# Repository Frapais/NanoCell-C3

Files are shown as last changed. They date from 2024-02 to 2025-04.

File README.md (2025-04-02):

# NanoCell-C3

This is the repository of my **NanoCell-C3** project, which includes an ESP32 development board I made to simplify the creation of small battery-powered devices for use with Home Assistant and ESPHome.
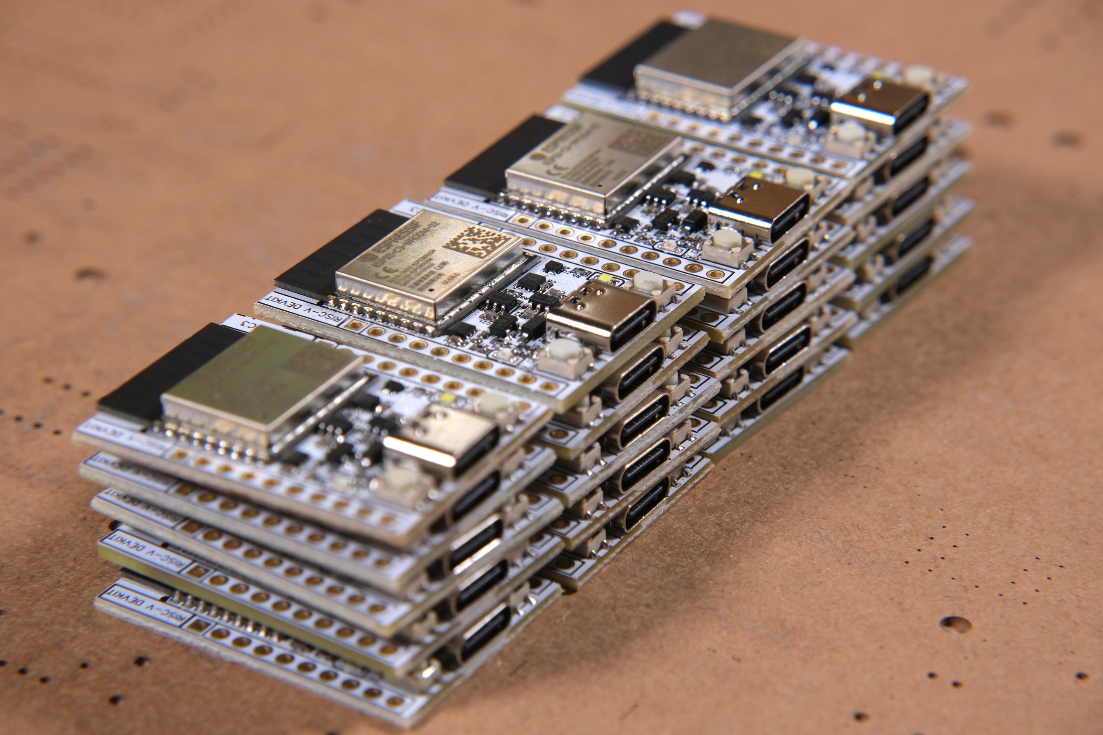
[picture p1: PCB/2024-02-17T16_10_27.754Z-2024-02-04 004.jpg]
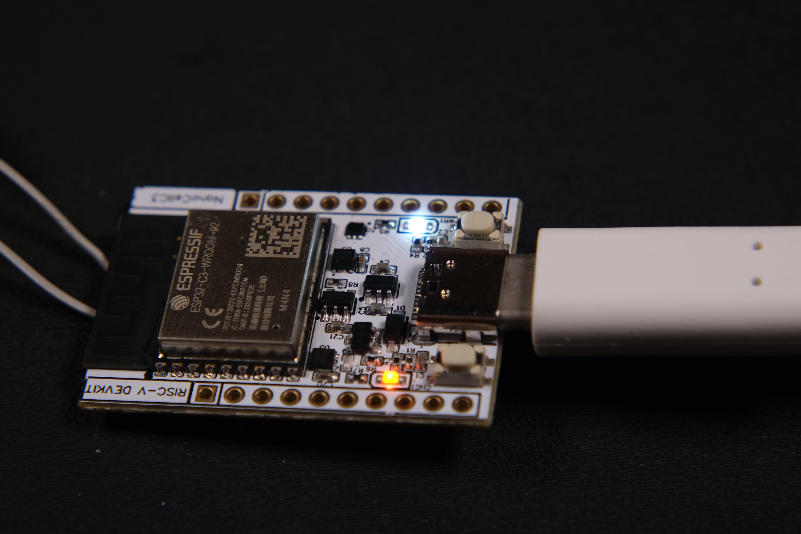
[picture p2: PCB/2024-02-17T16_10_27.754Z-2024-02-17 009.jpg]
|  |  |
|---|---|
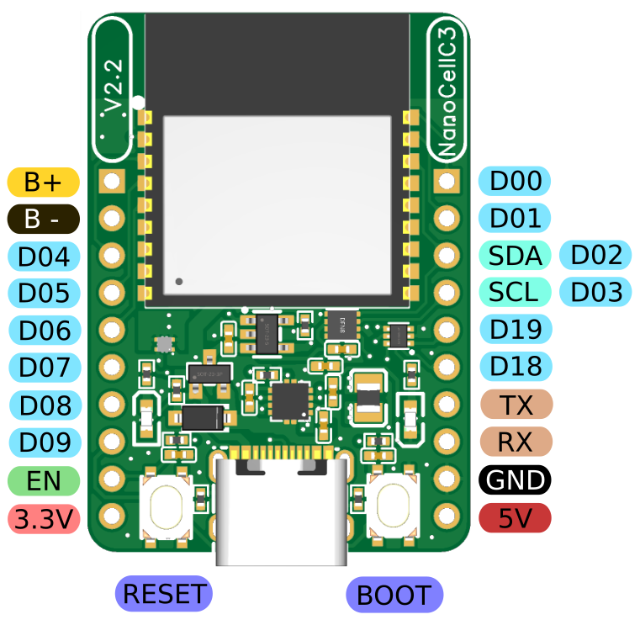
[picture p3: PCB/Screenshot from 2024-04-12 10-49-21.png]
Pinout
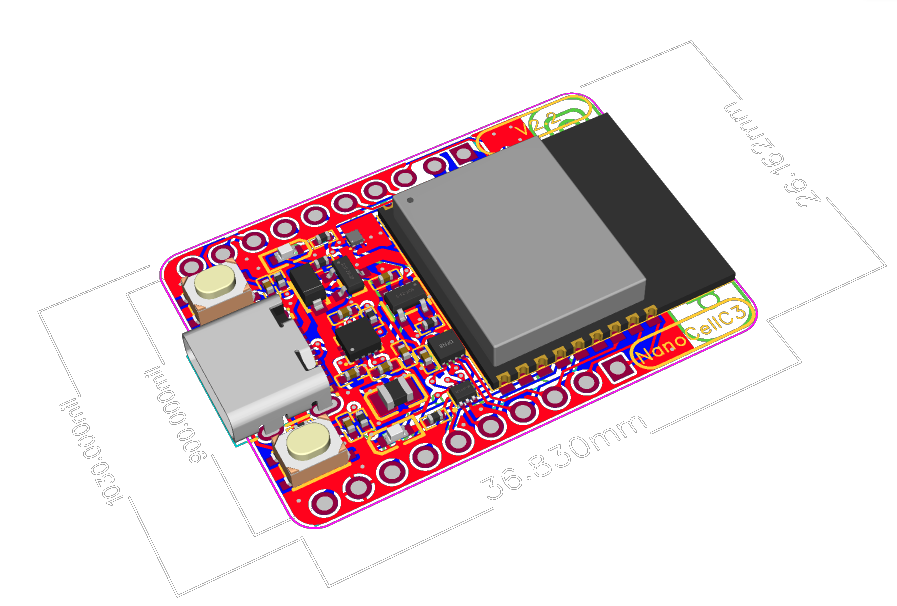
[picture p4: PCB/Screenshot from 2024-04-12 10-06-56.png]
Dimensions
|  |  |

## Description
### Hardware
#### Main Features
* Li-ion/Li-po battery charging & protection ICs
* Accurate battery capacity measurement IC, accessible via I2C on pins 2 and 3.
* USB Type-C port for charging and uploading firmware
* RESET and BOOT pushbuttons
* Charging and USB-power LED indicators
* Breadboard-compatible pin headers breaking out all the pins of ESP32-C3, as well as the USB, battery, and Vcc voltage.

### Tests
| Idle Power Consumption: 66.1μA | Max Charging Current: 464mA | VCC Output @ 4.2V input: 3.356V | VCC Output @ 3V input: 3.359V |
|---|---|---|---|
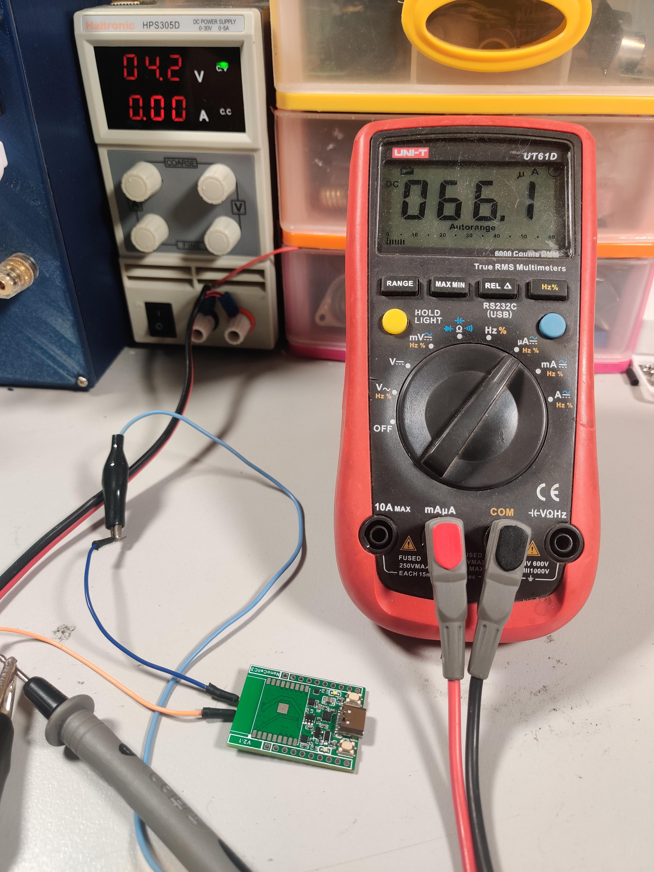
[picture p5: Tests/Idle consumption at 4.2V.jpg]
Idle Power Consumption
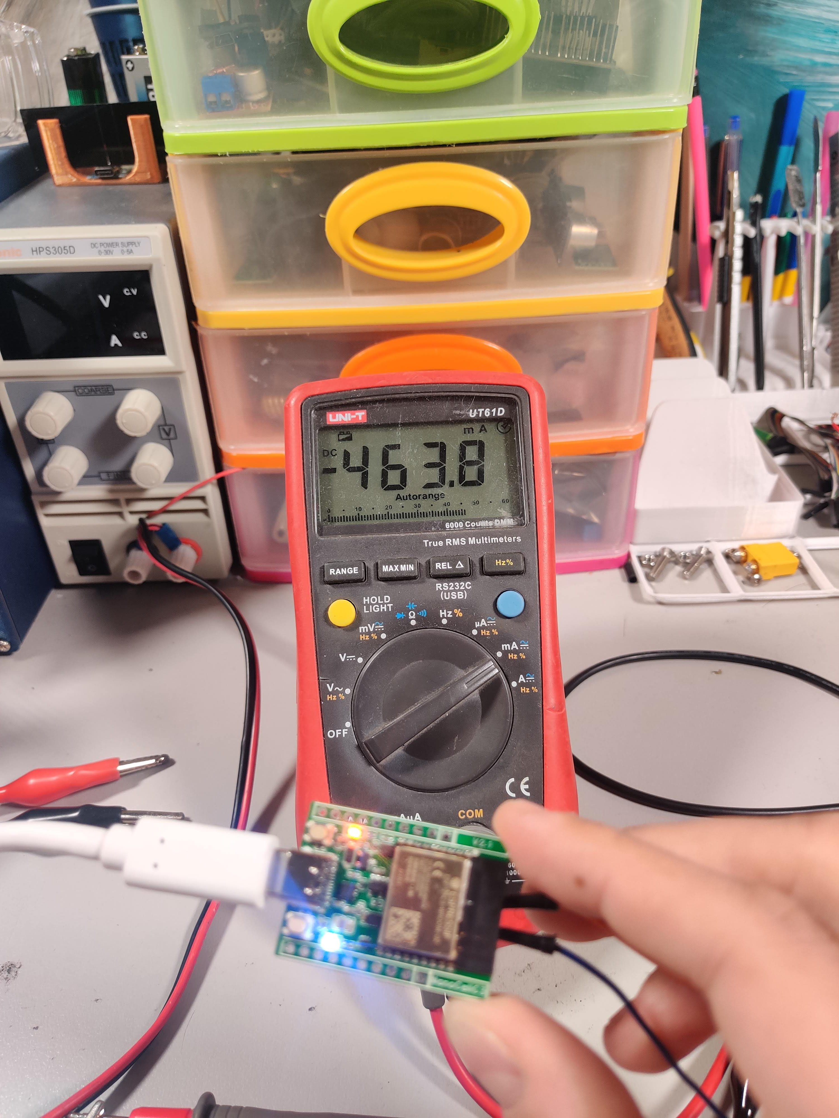
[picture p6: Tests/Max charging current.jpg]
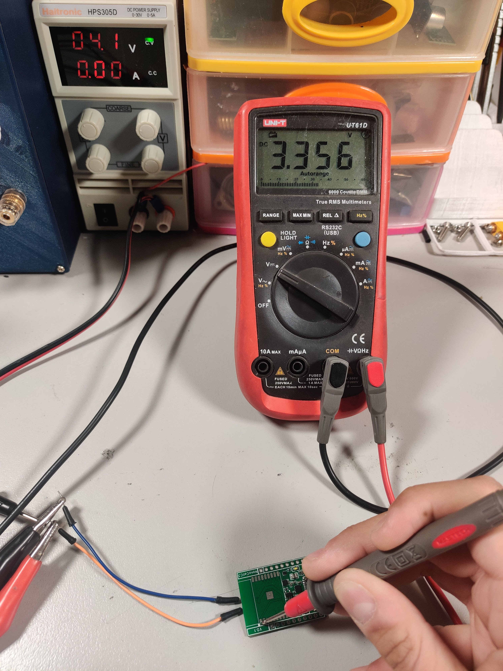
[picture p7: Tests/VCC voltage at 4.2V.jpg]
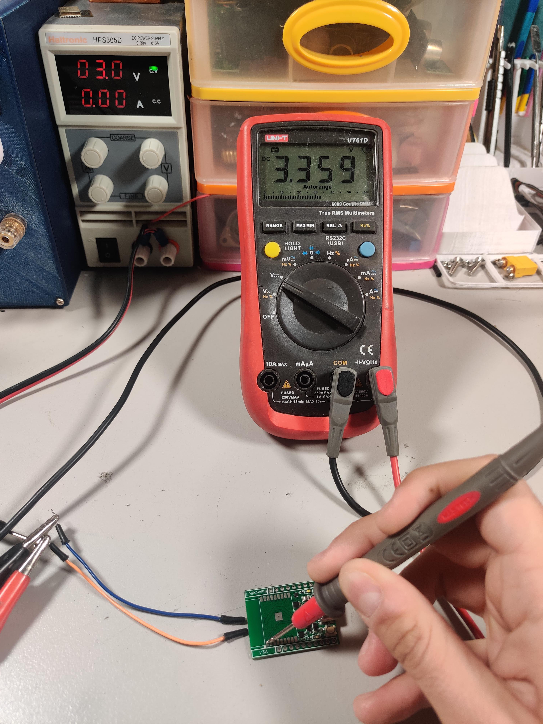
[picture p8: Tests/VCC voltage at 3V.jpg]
|  |  |  |  |

The Idle Power Consumption image shows the consumption of all the components of the board except the ESP32 module, as its consumption fluctuates depending on the tasks it's running. Therefore, if you want to calculate the battery life of your project, you should expect at least 66μA of current, in addition to the current consumption of the ESP32 module.

### Initial Home Assistant setup
#### Requirements:
* Access to Home Assistant Dashboard
* Installed ESPHome plugin

#### Setup process:
1. Connect the NanoCell-C3 board on the computer running Home Assistant, while pressing the BOOT button
2. Open ESPHome, and add a new device as shown [here](https://esphome.io/guides/getting_started_hassio#dashboard-interface)
3. Select "Connect" to upload the initialization firmware on the board, and select the correct port from the popup window. (It usually shows up as a "USB JTAG" device).
4. Wait for the upload to finish, and restart the NanoCell-C3. Now, every time you power on the device, it should connect to your WiFi automatically.
5. Last step, is to go to your Home Assistant settings, and Configure your newly discovered device (assuming it is powered on and visible on the network).

#### Video Tutorial:
https://youtu.be/UaIIV4CaRA4

### Battery Capacity Measurement
The NanoCell-C3 board features the MAX17048 battery capacity measurement IC connected to the respective I2C pins. As there is not complete support for this IC in the [ESPHome](https://esphome.io/index.html), you need to add it as a custom [ESPHome Component](https://esphome.io/components/sensor/custom)

#### I2C Pins of the NanoCell-C3 board
| Function | Pin No |
|---|---|
| SDA | 2 |
| SCL | 3 |

#### Setup process
Inside the [Home Assistant Setup](https://github.com/Frapais/NanoCell-C3/tree/main/Home%20Assistant%20Setup) folder, you will find a YAML file and a HEADER file.
* First, you must copy the header file to your Home Assistant under "/config/esphome/custom_components/MAX17048_component.h".
* Next, you have to create a new ESP32-C3 device from the ESPHome plugin, as described above. (If you haven't already).
* Inside the corresponding YAML file, you must paste the contents of this repo's [YAML]() file, replacing the "***" with your corresponding values.
  
Your YAML file needs to import the "MAX17048_component.h" file in the "includes" section, as well as the "Wire" library in the "libraries section.
Next, you can add an i2c sensor using the "custom" platform and include the corresponding "lambda" section to get the values from the MAX17048 Battery Measurement IC.

**Voila!** You can now monitor your battery status from Home Assistant with accuracy! I used Graphana to plot the Li-Ion battery's capacity over time in the following image:
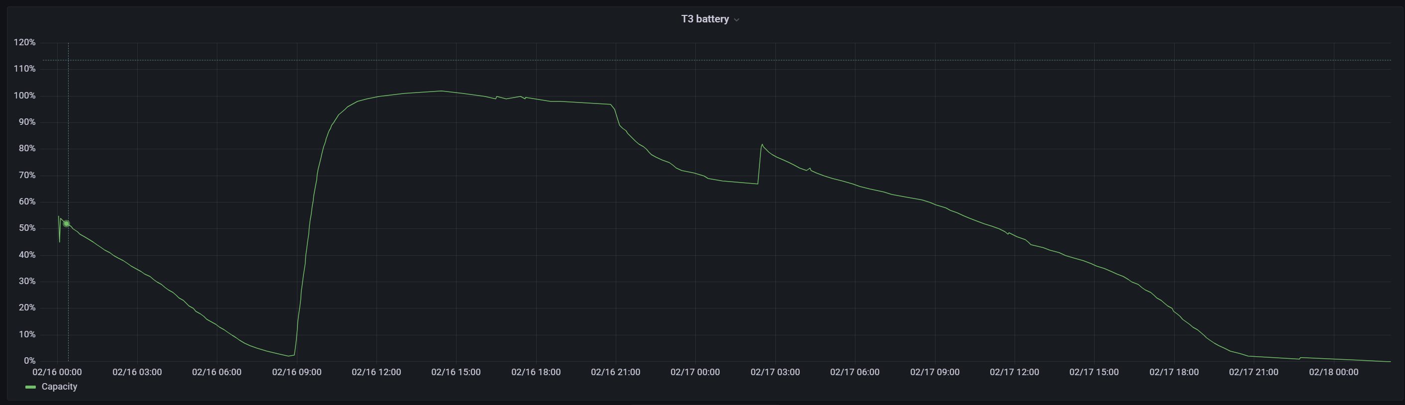
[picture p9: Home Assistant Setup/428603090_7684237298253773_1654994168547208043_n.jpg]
Battery Capacity Plot


## Availability
You can get the assembled boards in my [Tindie](https://www.tindie.com/products/frapais/esp32-devkit-nanocell-c3/), [Etsy](https://www.etsy.com/listing/1679895323/nanocell-c3-v2-beta?ref=listings_manager_grid), and [Elecrow](https://www.elecrow.com/nanocell-c3.html) stores.



## Certifications
This project is certified by the [Open Source Hardware Association (OSHWA)](https://certification.oshwa.org/gr000008.html)

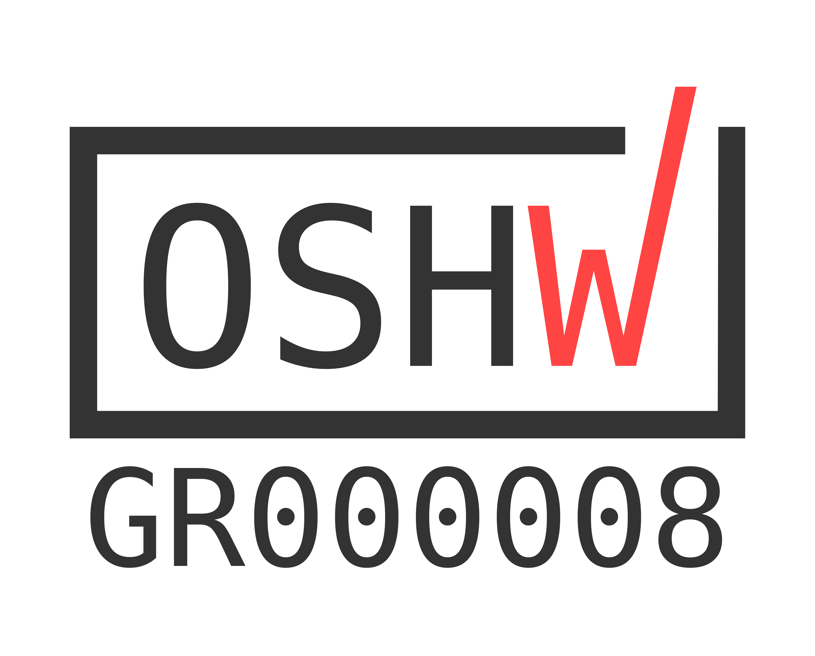
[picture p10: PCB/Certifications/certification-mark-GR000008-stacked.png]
Open Source Hardware Association Certification


## Support
If you find this project useful, please consider supporting me on any of the following platforms:
* PayPal:
  * <a href="https://www.paypal.com/paypalme/kostasparaskevas">
    
* Buy Me a Coffe:
  * <a href="https://www.buymeacoffee.com/spriglabs" target="_blank">Buy Me A Coffee</a>
* Instagram:
  * [@frapais.lab](https://www.instagram.com/sprig_labs/)

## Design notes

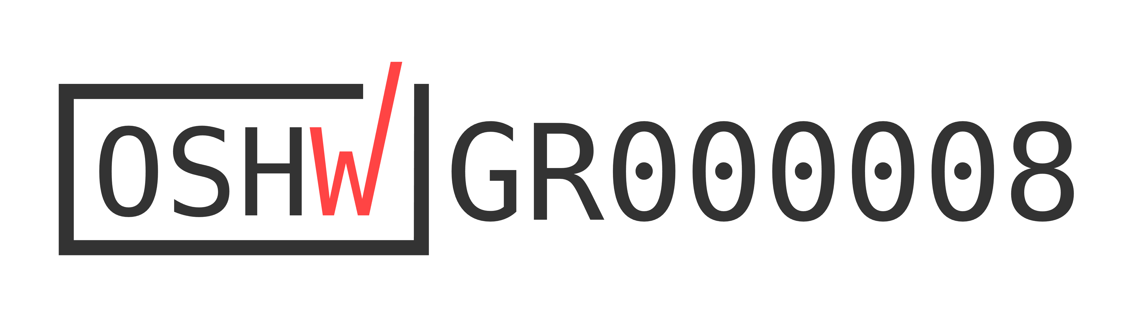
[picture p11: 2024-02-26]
PCB/Certifications/certification-mark-GR000008-wide.png

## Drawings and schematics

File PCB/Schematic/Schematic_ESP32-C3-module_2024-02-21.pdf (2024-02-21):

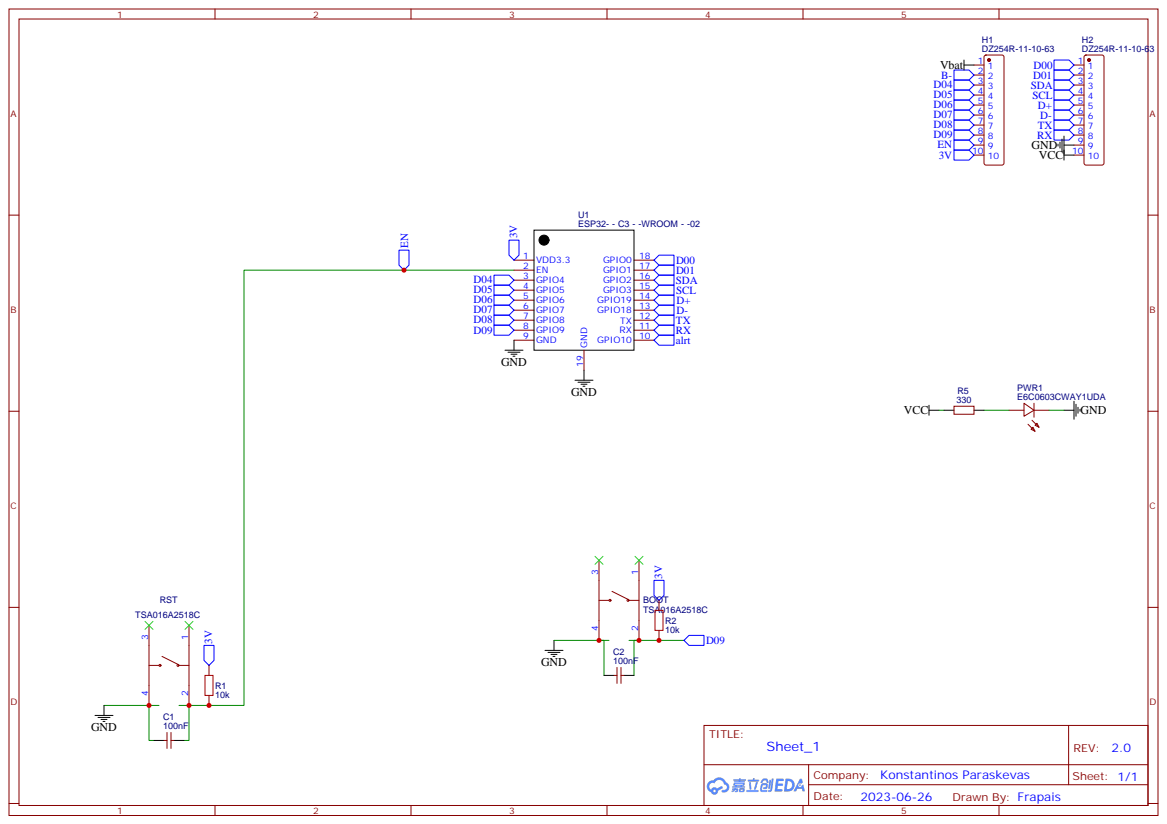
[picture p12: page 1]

## Voltage Regulator LiPo charger

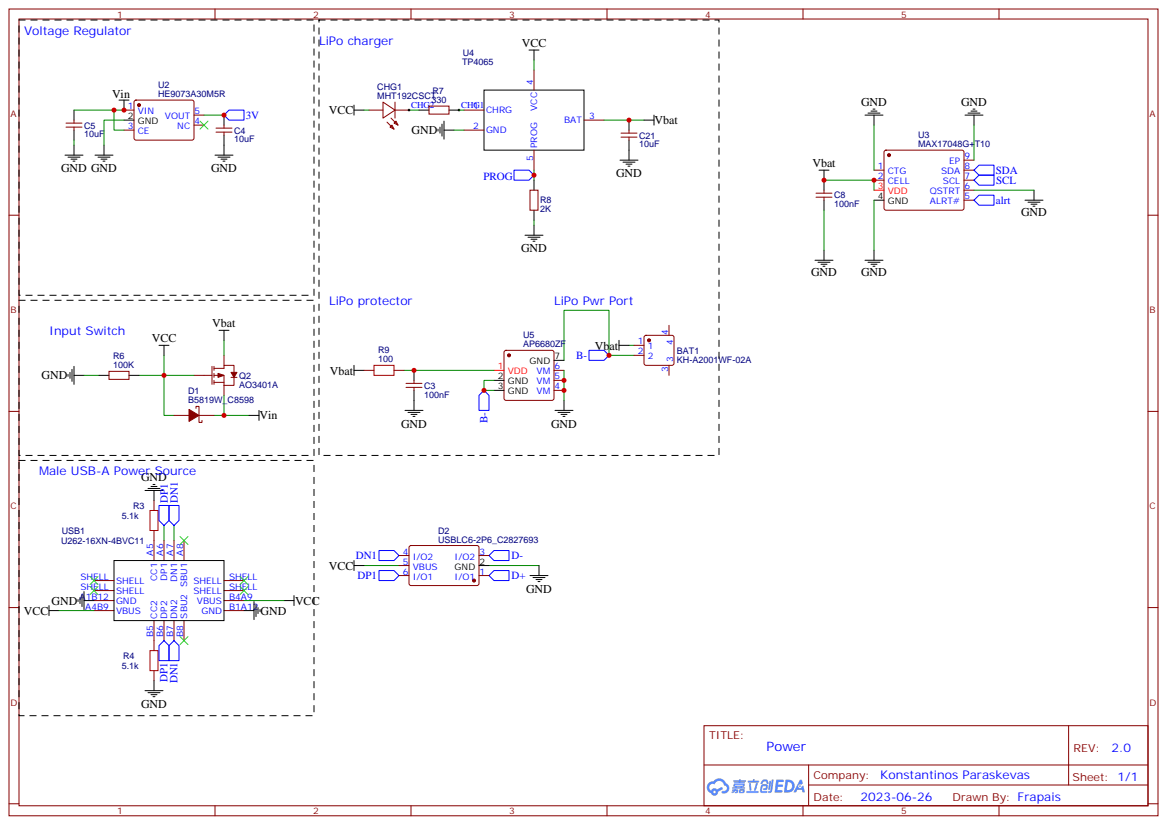
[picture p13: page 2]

Male USB-A Power Source

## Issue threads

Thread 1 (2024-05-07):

What is the actual input voltage operating range for the buck-boost converter?

DurvalMenezes, 2024-05-07:
As per the subject. I can see it works at least in LiPo cell range (3.0 -4.2V), but can it be fed from eg NiMH  cells (1.2V nominal voltage)? What about a 12V LiFePO4 4S battery bank?
This is of course dispensing with the charging functionality -- the LiFePO4 battery bank for example would be  kept charged by a solar panel setup.

Apologies in advance if that's somewhere in the docs/specs, but for the life of me I couldn't find it.

Frapais, 2024-05-07:
The buck-boost converter operates in the range of 2.5V to 5.5V, so NiMH cells may not be suitable. Additionally, for batteries with more than one cell, an appropriate balancing circuit should be added, as the integrated circuit is for charging single-cell Lithium batteries only. However, if you experiment with this, please share your results.

DurvalMenezes, 2024-05-07:
Thanks for the prompt and detailed response. Too bad the operating range is so restricted... it would be great if I could power it directly from the 12V bus I've already installed in my remote locations (fed from that battery bank which is then changed by solar panels).

Frapais, 2024-05-07:
Actually, that seems very useful. I might consider this feature for the next version. Thanks for noticing!

DurvalMenezes, 2024-05-07:
> Actually, that seems very useful. I might consider this feature for the next version. Thanks for noticing!

That would be perfect! 👍 if you can, please let me know by posting about it here in this issue, which I will be monitoring.

Thanks again!

Closed 2024-05-07.

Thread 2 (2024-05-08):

Battery and charger wiring diagram

bkanuka, 2024-05-08:
I'm interested in this project and I'm considering using it for controlling outdoor lights.

I'm a little unclear about what's required for wiring this to a battery and (potentially) solar panel.

- I can see that charging is available through USB. Is it ONLY through USB, or can I connect a voltage source (solar panel) directly?
- Which contacts are used for connecting the battery?
- What are the battery requirements? For example could this work with a 3.6v 18650 ?

Thanks!

Closed 2024-06-25.

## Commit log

2024-02-21 Uploaded schematic and PCB files
    [PCB_ESP32-C3-module_2_2024-02-21.pcbdoc]
2024-02-26 Updated PCB files & added OSHWA certification
    [PCB_ESP32-C3-module_2_2024-02-21.pcbdoc, PCB_ESP32-C3-module_2_2024-02-26.pcbdoc]
2025-04-09 Updated HA Setup for Battery Fuel Gauge IC
    Although the NanoCell uses the MAX17048 battery fuel gauge IC, the already implemented MAX17043 component from ESPHome works adequately well without much effort. To fully take advantage of the MAX170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
